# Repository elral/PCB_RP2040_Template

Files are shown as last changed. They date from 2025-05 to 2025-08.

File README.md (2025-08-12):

# RP2040 Base PCB design

This KiCad template contains a base RP2040 schematic and PCB layout. To use this template go to _File_ > _New Project From Template..._,
switch to the _User Templates_ tab, then click the folder icon and navigate to this folder.

JLCPCB component numbers and footprints are included in the schematic as custom symbol properties.

**WARNING** While I've made a PCB using this design it was not done using this exact template. No boards have been ordered yet using this template so
if you use it and place an order while this message is still in place it is at your own risk.

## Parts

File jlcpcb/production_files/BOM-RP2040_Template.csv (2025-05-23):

Comment | Designator | Footprint | LCSC | Quantity
1k | R1,R2 | R_0402_1005Metric | C11702 | 2
100n | C11,C12,C13,C14,C15,C3,C6,C7,C9 | C_0402_1005Metric | C1525 | 9
10u | C1,C2 | C_0402_1005Metric | C15525 | 2
RP2040 | U1 | QFN56P40_700X700X90L40X18T310N | C2040 | 1
27 | R3,R4 | R_0402_1005Metric | C25100 | 2
10k | R6 | R_0402_1005Metric | C25744 | 1
5.1k | R7,R8 | R_0402_1005Metric | C25905 | 2
USB_C_Receptacle_USB2.0_16P | J3 | USB_C_Receptacle_HCTL_HC-TYPE-C-16P-01A | C2997432 | 1
BOOT_SEL | SW1,SW2 | SW_Push_1P1T_XKB_TS-1187A | C318884 | 2
10pF | C4,C5 | C_0402_1005Metric | C32949 | 2
1uF | C10,C8 | C_0402_1005Metric | C52923 | 2
AMS1117-3.3 | U2 | SOT-223-3_TabPin2 | C6186 | 1
D_Schottky | D1 | D_SOD-123 | C8598 | 1
X322512MSB4SI | Y1 | Crystal_SMD_3225-4Pin_3.2x2.5mm | C9002 | 1
W25Q16JVSS | U4 | SOIC-8_5.23x5.23mm_P1.27mm | C97521 | 1
DNF | R5 | R_0805_2012Metric_Pad1.20x1.40mm_HandSolder |  | 1
D15-D29 | J2 | PinHeader_1x15_P2.54mm_Vertical |  | 1
PWR-Supply | J5 | PinHeader_1x04_P2.54mm_Vertical |  | 1
D0-D14 | J1 | PinHeader_1x15_P2.54mm_Vertical |  | 1

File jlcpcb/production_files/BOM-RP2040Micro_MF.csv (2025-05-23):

Comment | Designator | Footprint | LCSC | Quantity
1k | R1,R2 | R_0402_1005Metric | C11702 | 2
100n | C11,C12,C13,C14,C15,C3,C6,C7,C9 | C_0402_1005Metric | C1525 | 9
10u | C1,C2 | C_0402_1005Metric | C15525 | 2
Conn_01x02_Pin | J2 | JST_XH_B2B-XH-A_1x02_P2.50mm_Vertical | C20079 | 1
RP2040 | U1 | QFN56P40_700X700X90L40X18T310N | C2040 | 1
27 | R3,R4 | R_0402_1005Metric | C25100 | 2
10k | R6 | R_0402_1005Metric | C25744 | 1
5.1k | R7,R8 | R_0402_1005Metric | C25905 | 2
W25Q16JVSS | U4 | Winbond_USON-8-1EP_3x2mm_P0.5mm_EP0.2x1.6mm | C2843335 | 1
Conn_01x02_Pin | J7,J8 | JST_ZH_B2B-ZR_1x02_P1.50mm_Vertical | C2845550 | 2
USB_C_Receptacle_USB2.0_16P | J3 | USB_C_Receptacle_HCTL_HC-TYPE-C-16P-01A | C2997432 | 1
10pF | C4,C5 | C_0402_1005Metric | C32949 | 2
AMS1117-3.3 | U2 | SOT-89-3 | C347256 | 1
1uF | C10,C8 | C_0402_1005Metric | C52923 | 2
D_Schottky | D1 | D_SOD-123 | C5377901 | 1
X322512MSB4SI | Y1 | Crystal_SMD_3225-4Pin_3.2x2.5mm | C9002 | 1
DNF | R5 | R_0805_2012Metric_Pad1.20x1.40mm_HandSolder |  | 1
ProMicro | U5 | ProMicro |  | 1

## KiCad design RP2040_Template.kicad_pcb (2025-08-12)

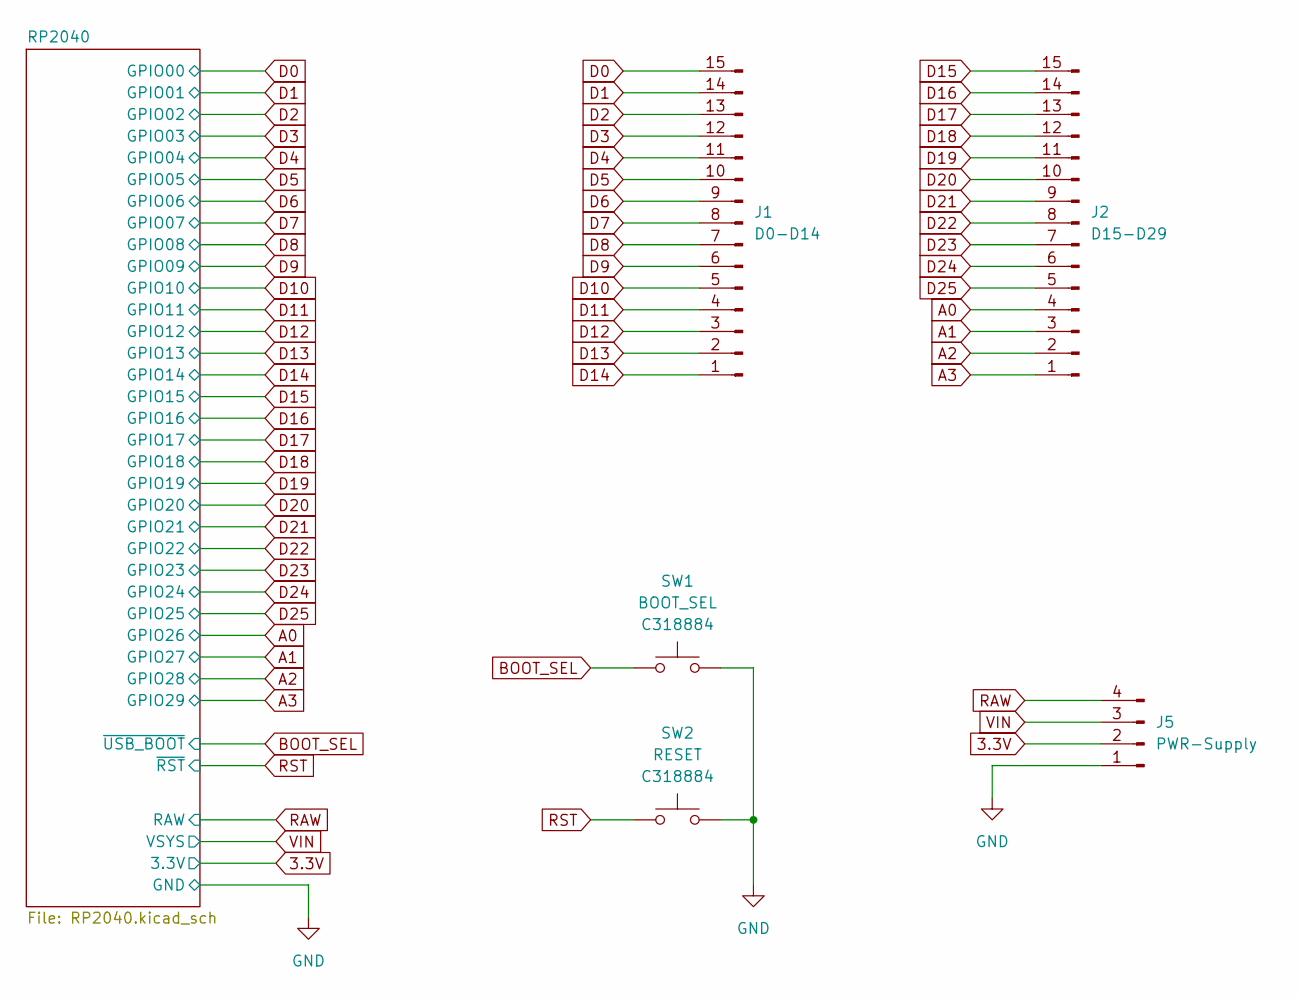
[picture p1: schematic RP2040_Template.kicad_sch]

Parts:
J1: D0-D14; PinHeader_1x15_P2.54mm_Vertical
J2: D15-D29; PinHeader_1x15_P2.54mm_Vertical
J5: PWR-Supply; PinHeader_1x04_P2.54mm_Vertical
SW1: BOOT_SEL; SW_Push_1P1T_XKB_TS-1187A; JLCPCB C318884
SW2: RESET; SW_Push_1P1T_XKB_TS-1187A; JLCPCB C318884

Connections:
3.3V: J5.2; also elsewhere on the board
A0: J2.4; also elsewhere on the board
A1: J2.3; also elsewhere on the board
A2: J2.2; also elsewhere on the board
A3: J2.1; also elsewhere on the board
BOOT_SEL: SW1.1; also elsewhere on the board
D0: J1.15; also elsewhere on the board
D1: J1.14; also elsewhere on the board
D2: J1.13; also elsewhere on the board
D3: J1.12; also elsewhere on the board
D4: J1.11; also elsewhere on the board
D5: J1.10; also elsewhere on the board
D6: J1.9; also elsewhere on the board
D7: J1.8; also elsewhere on the board
D8: J1.7; also elsewhere on the board
D9: J1.6; also elsewhere on the board
D10: J1.5; also elsewhere on the board
D11: J1.4; also elsewhere on the board
D12: J1.3; also elsewhere on the board
D13: J1.2; also elsewhere on the board
D14: J1.1; also elsewhere on the board
D15: J2.15; also elsewhere on the board
D16: J2.14; also elsewhere on the board
D17: J2.13; also elsewhere on the board
D18: J2.12; also elsewhere on the board
D19: J2.11; also elsewhere on the board
D20: J2.10; also elsewhere on the board
D21: J2.9; also elsewhere on the board
D22: J2.8; also elsewhere on the board
D23: J2.7; also elsewhere on the board
D24: J2.6; also elsewhere on the board
D25: J2.5; also elsewhere on the board
GND: J5.1, SW1.2, SW2.2; also elsewhere on the board
RAW: J5.4; also elsewhere on the board
RST: SW2.1; also elsewhere on the board
VIN: J5.3; also elsewhere on the board

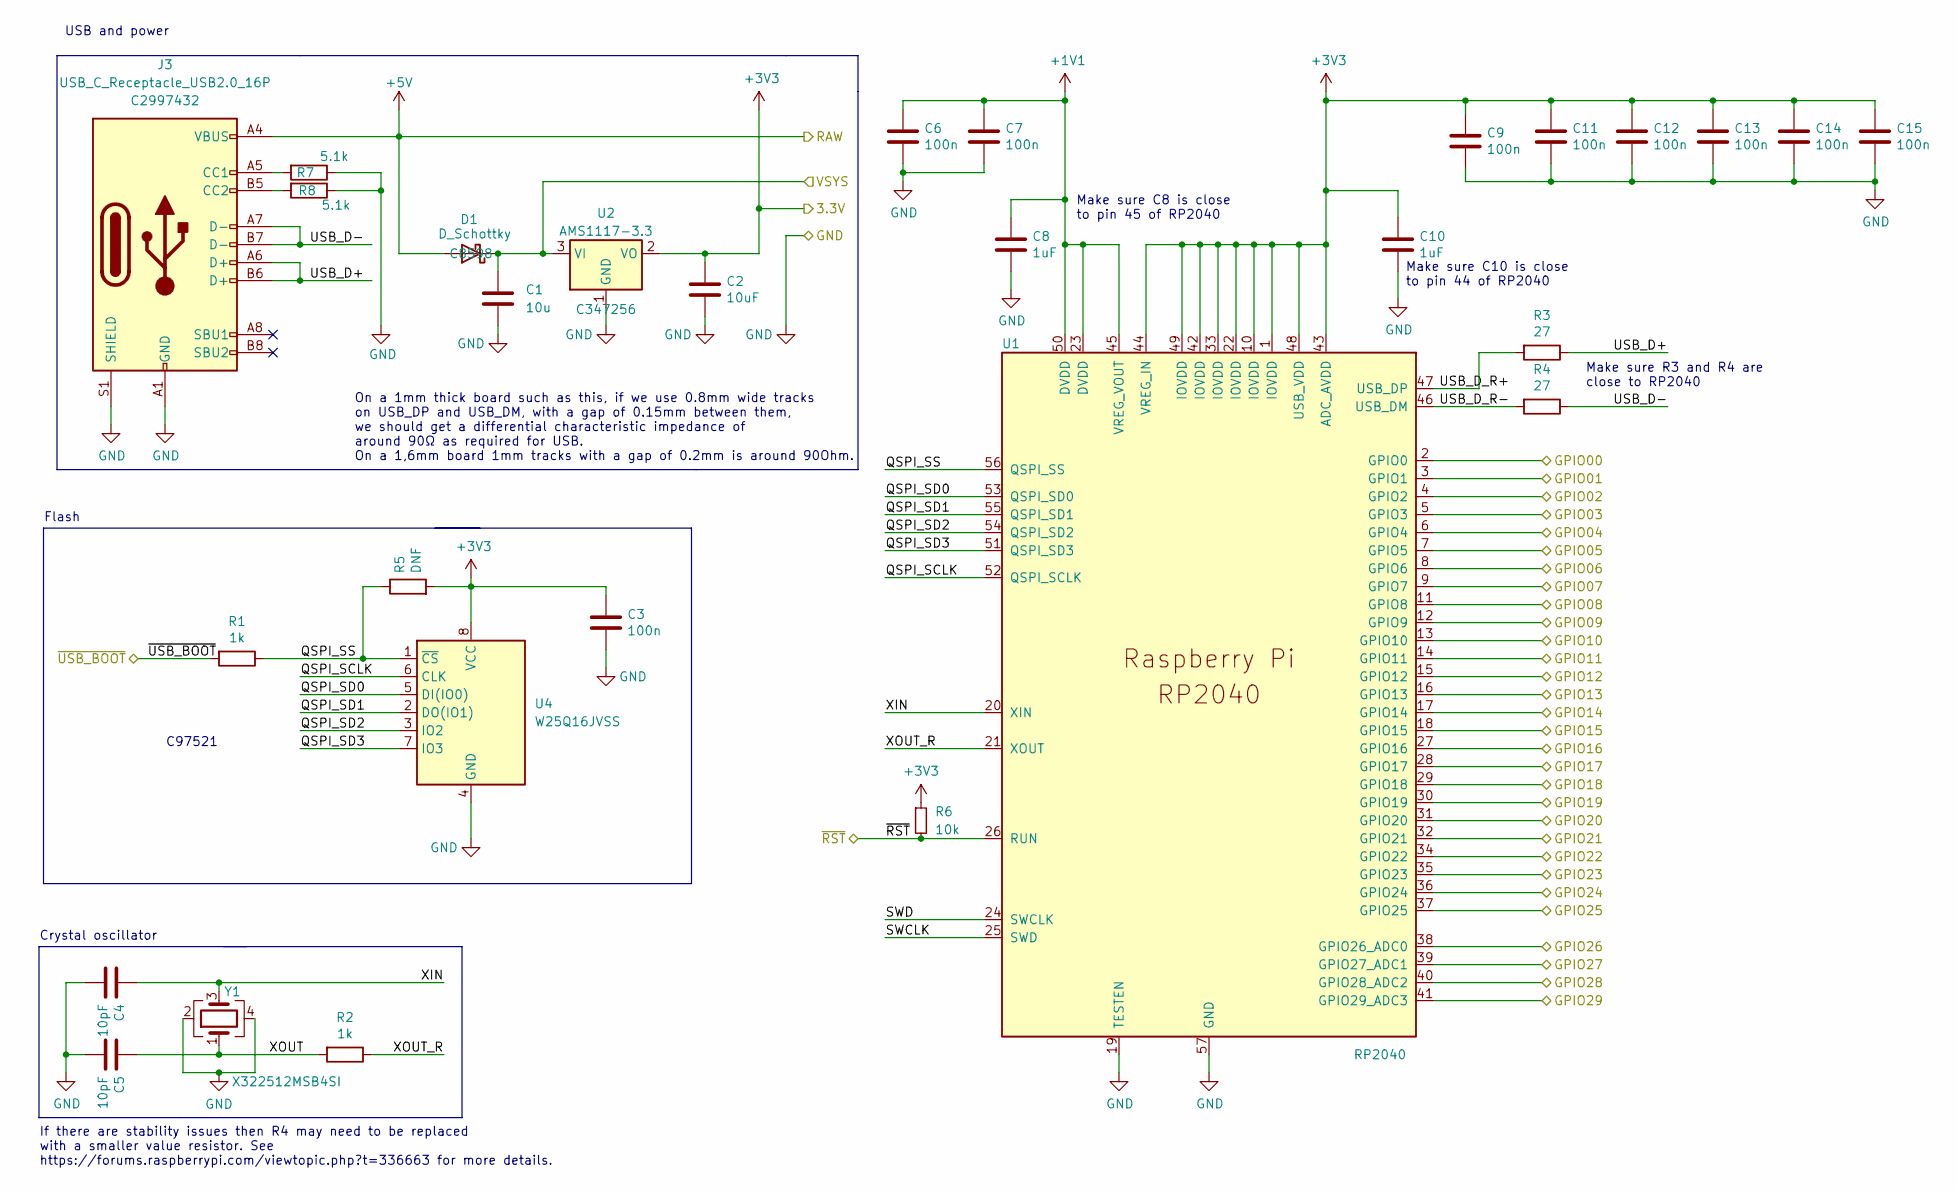
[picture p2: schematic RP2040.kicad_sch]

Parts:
C1: 10u; C_0402_1005Metric
C2: 10uF; C_0402_1005Metric; MPN - JLCPCB C52923
C3, C6, C7, C9, C11, C12, C13, C14, C15: 100n; C_0402_1005Metric; MPN - JLCPCB C52923
C4, C5: 10pF; C_0402_1005Metric; MPN - JLCPCB C32949
C8, C10: 1uF; C_0402_1005Metric; MPN - JLCPCB C52923
D1: D_Schottky; D_SOD-123; JLCPCB C8598
J3: USB_C_Receptacle_USB2.0_16P; USB_C_Receptacle_HCTL_HC-TYPE-C-16P-01A; JLCPCB C2997432
R1, R2: 1k; R_0402_1005Metric; MPN - JLCPCB C11702
R3, R4: 27; R_0402_1005Metric; MPN - JLCPCB C25190
R5: DNF; R_0805_2012Metric_Pad1.20x1.40mm_HandSolder
R6: 10k; R_0402_1005Metric; MPN - JLCPCB C25744
R7, R8: 5.1k; R_0402_1005Metric; MPN - JLCPCB C11702
U1: RP2040; QFN56P40_700X700X90L40X18T310N; MPN - JLCPCB C2040
U2: AMS1117-3.3; SOT-223-3_TabPin2; MPN - JLCPCB C6186; JLCPCB C347256
U4: W25Q16JVSS; SOIC-8_5.23x5.23mm_P1.27mm; JLCPCB C2843335
Y1: X322512MSB4SI; Crystal_SMD_3225-4Pin_3.2x2.5mm; MPN - JLCPCB C9002

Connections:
3.3V: C2.1, C3.1, C9.1, C10.1, C11.1, C12.1, C13.1, C14.1, C15.1, R5.2, R6.1, U1.1 (IOVDD), U1.10 (IOVDD), U1.22 (IOVDD), U1.33 (IOVDD), U1.42 (IOVDD), U1.43 (ADC_AVDD), U1.44 (VREG_IN), U1.48 (USB_VDD), U1.49 (IOVDD), U2.2 (VO), U4.8 (VCC); also elsewhere on the board
+1V1: C6.1, C7.1, C8.1, U1.23 (DVDD), U1.45 (VREG_VOUT), U1.50 (DVDD)
/RP2040/QSPI_SCLK: U1.52 (QSPI_SCLK), U4.6 (CLK)
/RP2040/QSPI_SD0: U1.53 (QSPI_SD0), U4.5 (DI(IO0))
/RP2040/QSPI_SD1: U1.55 (QSPI_SD1), U4.2 (DO(IO1))
/RP2040/QSPI_SD2: U1.54 (QSPI_SD2), U4.3 (IO2)
/RP2040/QSPI_SD3: U1.51 (QSPI_SD3), U4.7 (IO3)
/RP2040/QSPI_SS: R1.1, R5.1, U1.56 (QSPI_SS), U4.1 (~CS)
/RP2040/SWCLK: U1.25 (SWD)
/RP2040/SWD: U1.24 (SWCLK)
/RP2040/USB_D+: J3.A6 (D+), J3.B6 (D+), R3.1
/RP2040/USB_D-: J3.A7 (D-), J3.B7 (D-), R4.1
/RP2040/USB_D_R+: R3.2, U1.47 (USB_DP)
/RP2040/USB_D_R-: R4.2, U1.46 (USB_DM)
/RP2040/XIN: C4.1, U1.20 (XIN), Y1.3
/RP2040/XOUT: C5.1, R2.2, Y1.1
/RP2040/XOUT_R: R2.1, U1.21 (XOUT)
A0: U1.38 (GPIO26_ADC0); also elsewhere on the board
A1: U1.39 (GPIO27_ADC1); also elsewhere on the board
A2: U1.40 (GPIO28_ADC2); also elsewhere on the board
A3: U1.41 (GPIO29_ADC3); also elsewhere on the board
BOOT_SEL: R1.2; also elsewhere on the board
D0: U1.2 (GPIO0); also elsewhere on the board
D1: U1.3 (GPIO1); also elsewhere on the board
D2: U1.4 (GPIO2); also elsewhere on the board
D3: U1.5 (GPIO3); also elsewhere on the board
D4: U1.6 (GPIO4); also elsewhere on the board
D5: U1.7 (GPIO5); also elsewhere on the board
D6: U1.8 (GPIO6); also elsewhere on the board
D7: U1.9 (GPIO7); also elsewhere on the board
D8: U1.11 (GPIO8); also elsewhere on the board
D9: U1.12 (GPIO9); also elsewhere on the board
D10: U1.13 (GPIO10); also elsewhere on the board
D11: U1.14 (GPIO11); also elsewhere on the board
D12: U1.15 (GPIO12); also elsewhere on the board
D13: U1.16 (GPIO13); also elsewhere on the board
D14: U1.17 (GPIO14); also elsewhere on the board
D15: U1.18 (GPIO15); also elsewhere on the board
D16: U1.27 (GPIO16); also elsewhere on the board
D17: U1.28 (GPIO17); also elsewhere on the board
D18: U1.29 (GPIO18); also elsewhere on the board
D19: U1.30 (GPIO19); also elsewhere on the board
D20: U1.31 (GPIO20); also elsewhere on the board
D21: U1.32 (GPIO21); also elsewhere on the board
D22: U1.34 (GPIO22); also elsewhere on the board
D23: U1.35 (GPIO23); also elsewhere on the board
D24: U1.36 (GPIO24); also elsewhere on the board
D25: U1.37 (GPIO25); also elsewhere on the board
GND: C1.2, C2.2, C3.2, C4.2, C5.2, C6.2, C7.2, C8.2, C9.2, C10.2, C11.2, C12.2, C13.2, C14.2, C15.2, J3.A1 (GND), J3.A12 (GND), J3.B1 (GND), J3.B12 (GND), J3.S1 (SHIELD), R7.1, R8.1, U1.19 (TESTEN), U1.57 (GND), U2.1 (GND), U4.4 (GND), Y1.2, Y1.4; also elsewhere on the board
unnamed: J3.A5 (CC1), R7.2
unnamed: J3.B5 (CC2), R8.2
RAW: D1.2 (A), J3.A4 (VBUS), J3.A9 (VBUS), J3.B4 (VBUS), J3.B9 (VBUS); also elsewhere on the board
RST: R6.2, U1.26 (RUN); also elsewhere on the board
VIN: C1.1, D1.1 (K), U2.3 (VI); also elsewhere on the board

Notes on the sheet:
Make sure C8 is close to pin 45 of RP2040
USB and power
Make sure C10 is close to pin 44 of RP2040
Make sure R3 and R4 are close to RP2040
C97521
If there are stability issues then R4 may need to be replaced with a smaller value resistor. See https://forums.raspberrypi.com/viewtopic.php?t=336663 for more details.
On a 1mm thick board such as this, if we use 0.8mm wide tracks on USB_DP and USB_DM, with a gap of 0.15mm between them, we should get a differential characteristic impedance of around 90Ω as required for USB. On a 1,6mm board 1mm tracks with a gap of 0.2mm is around 90Ohm.
Flash
Crystal oscillator

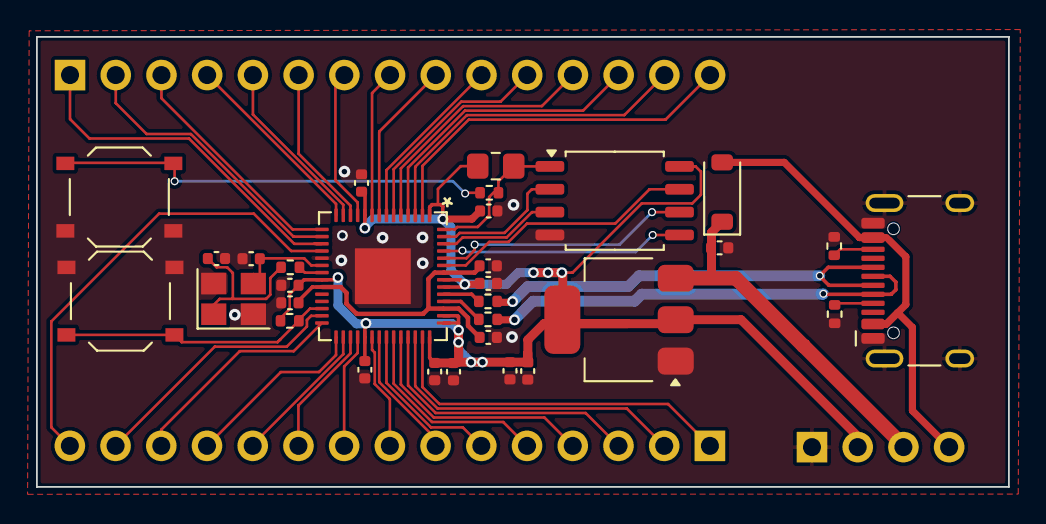
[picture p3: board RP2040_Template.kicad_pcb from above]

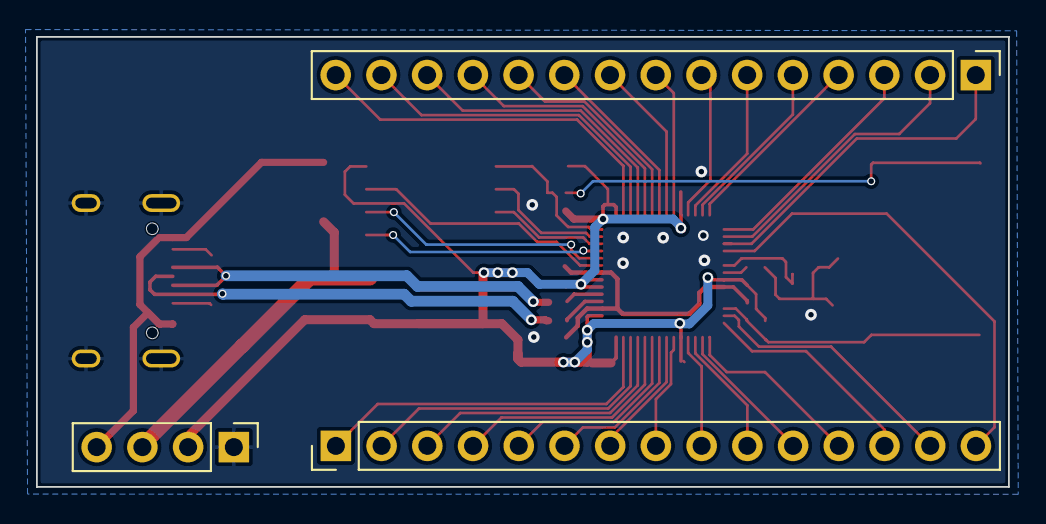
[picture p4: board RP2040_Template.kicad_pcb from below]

Board: 2 copper layers, 54.0 x 25.0 mm, 34 parts (3 on the bottom side), 52 nets.

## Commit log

2025-05-24 exclude KiCad auto generated files
2025-08-12 Update to KiCad Version 9
    [RP2040.kicad_sch, RP2040_Template.kicad_pcb, RP2040_Template.kicad_sch]
